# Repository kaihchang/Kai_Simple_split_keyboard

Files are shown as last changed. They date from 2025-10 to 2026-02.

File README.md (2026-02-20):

# Kai Simple, an easy-to-build diodeless, wireless split keyboard

Kai Simple is a cradio (or some call it Sweep) variation that fits author's hands best.
Author's first KB design: https://github.com/kaihchang/Ascend_splay_split_keyboard

👉 ZMK config | [Dongle-less](https://github.com/kaihchang/zmk-config-kai-simple) | [With Dongle](https://github.com/kaihchang/zmk-config-kai-simple-dongle)

MCUs face up for englmaxi's ZMK on-board LED widget. Front-facing built-in LEDs are utilized to present battery and connection status. I use n!n replicas, they only have 1 led each, so sadly no layer change indication.

| Images             |
:-------------------------:
New v4 case available!
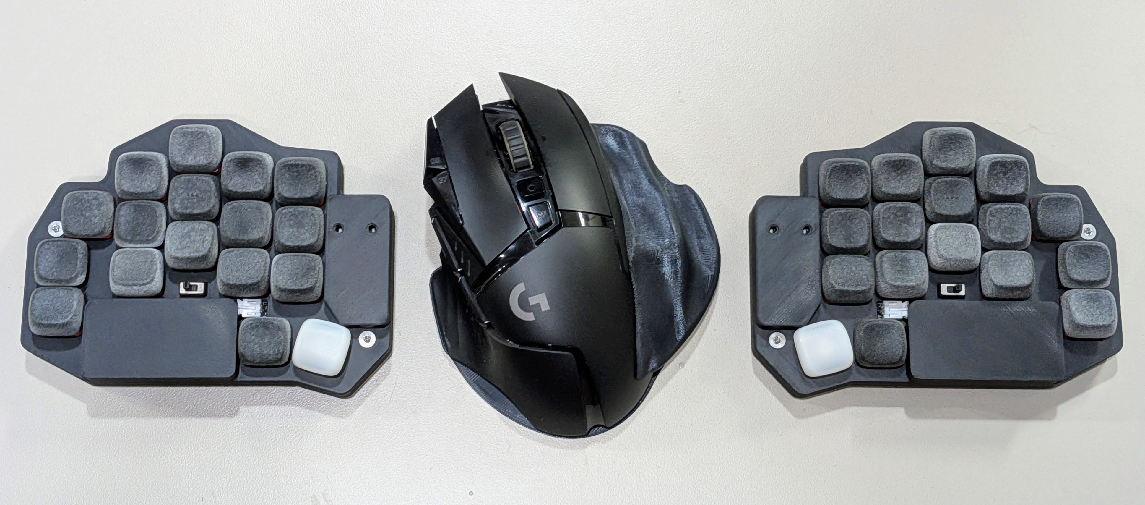
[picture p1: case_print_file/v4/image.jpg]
v4_case
|
|
  |
  |
螢幕擷取畫面 2024-04-08 094835  |

I've been using my last Ascend KB for a month, while it is comfortable, MX switches are still relatively big and wide. Maybe it's bc I have small hands or was used to Sweep before it, I started missing Chocs, so that's why there's this Simple.
I'll probably stick with ZMK but just in case something went wrong with the power circuits (unlikely), I left a pin for TRRS connectors.

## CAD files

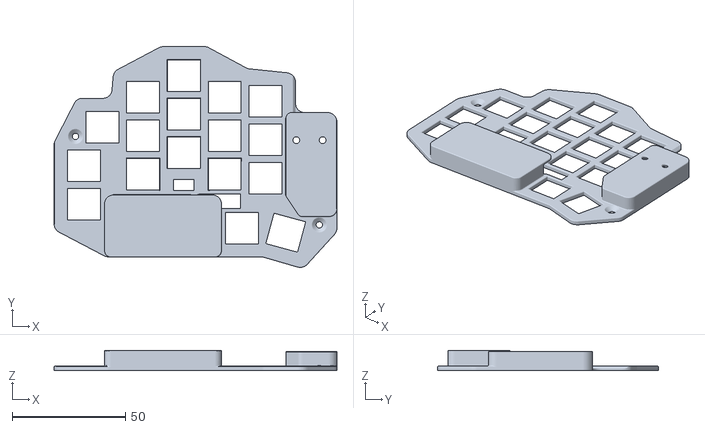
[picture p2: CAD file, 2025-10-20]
case_print_file/v4/upper_case_left.stl
124.9 x 97.5 x 8.89

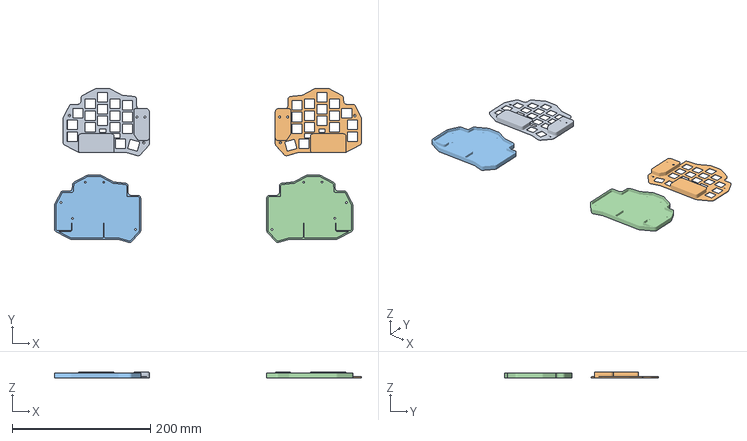
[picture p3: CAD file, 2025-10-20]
case_print_file/v4/kai_simple_cases_v4.3mf
444.6 x 223.0 x 8.89 mm
upper_case_left.stl x 2
lower_case_left.stl x 2

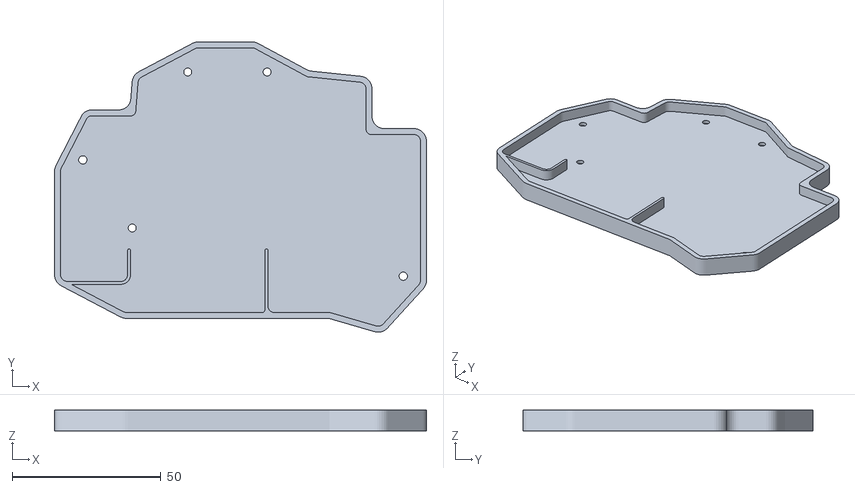
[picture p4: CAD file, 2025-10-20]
case_print_file/v4/lower_case_left.stl
124.9 x 97.5 x 7.00

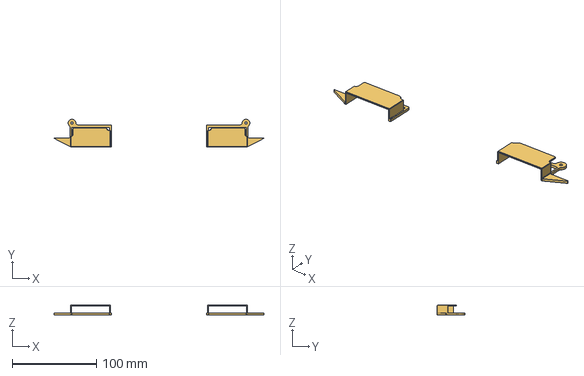
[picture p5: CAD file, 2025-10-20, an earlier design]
case_print_file/v1/v1_battery_cover.step
249.3 x 32.7 x 12.0 mm

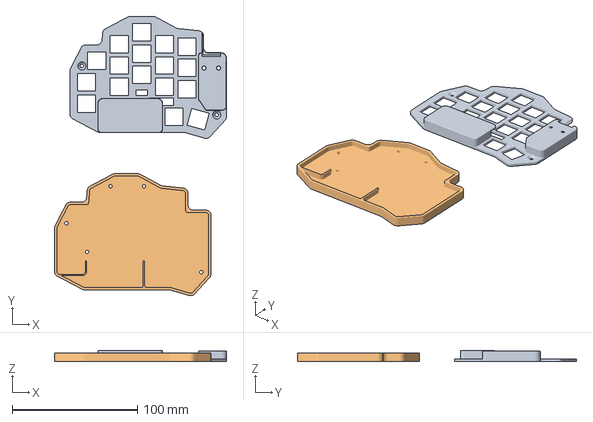
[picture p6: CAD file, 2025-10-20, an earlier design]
case_print_file/v3/kai_simple_cases_v3.3mf
137.3 x 223.0 x 8.89 mm
upper_case_left.stl
lower_case_left.stl

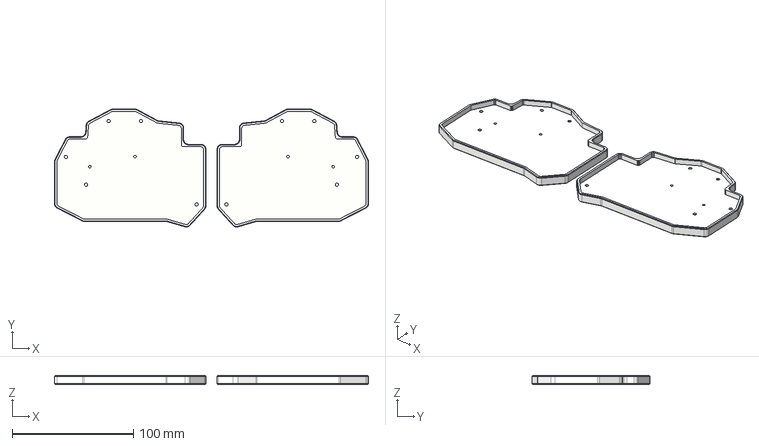
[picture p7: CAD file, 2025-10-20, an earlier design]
case_print_file/v1/v1_case.step
258.5 x 97.2 x 7.10 mm

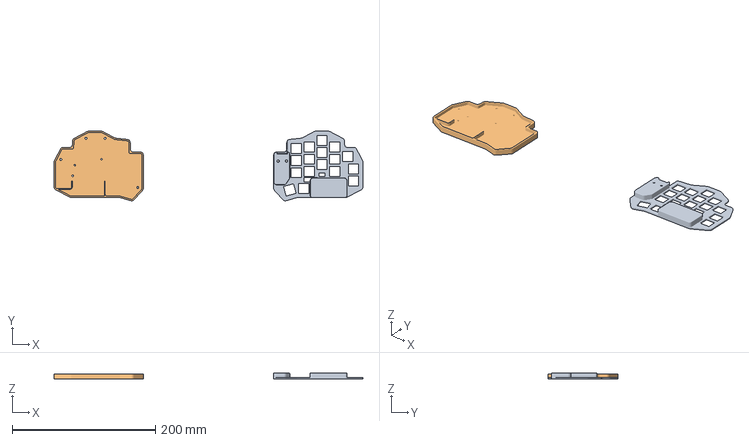
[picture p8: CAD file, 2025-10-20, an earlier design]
case_print_file/v2/kai_simple_cases_v2.3mf
432.1 x 97.5 x 8.89 mm
upper_case_left.stl
lower_case_left.stl

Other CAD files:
case_print_file/v2/upper_case_left.stl
case_print_file/v3/upper_case_left.stl

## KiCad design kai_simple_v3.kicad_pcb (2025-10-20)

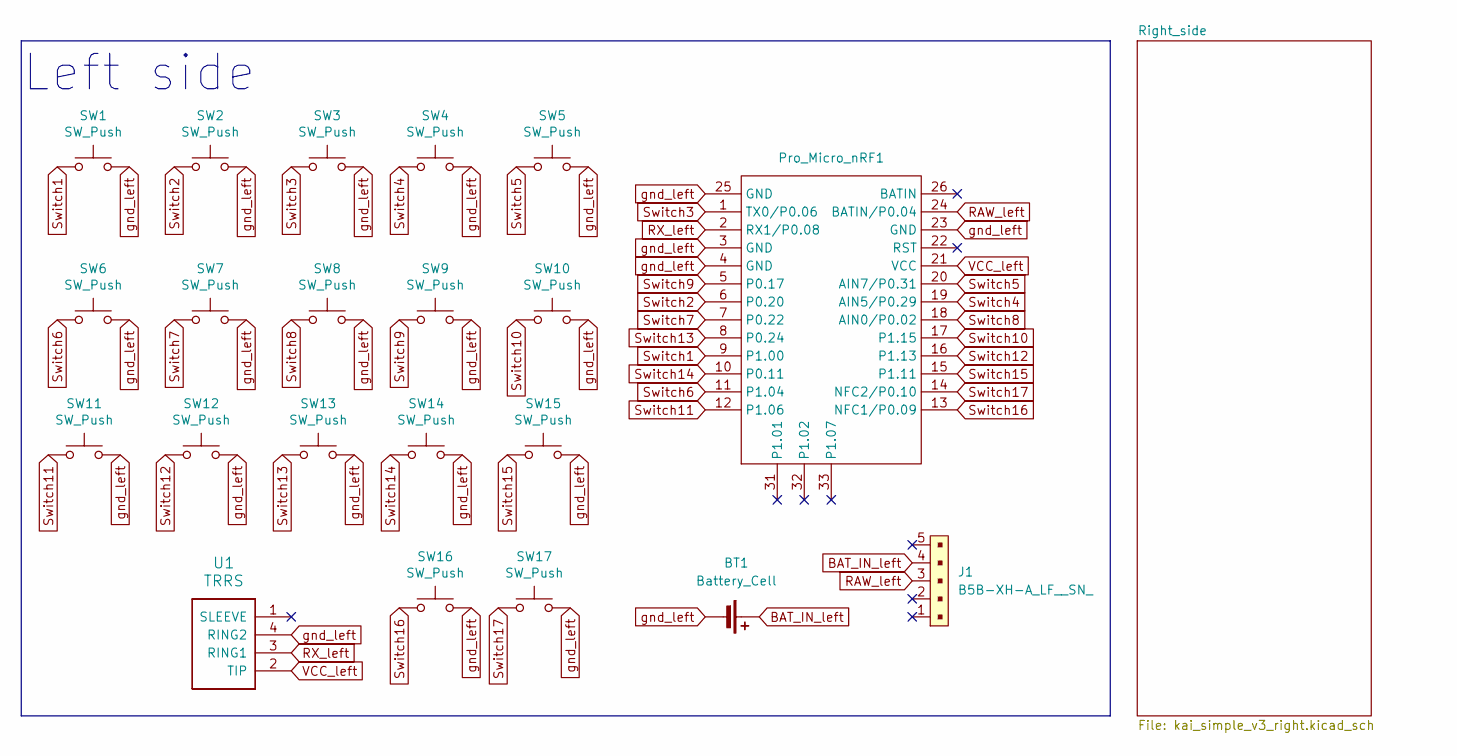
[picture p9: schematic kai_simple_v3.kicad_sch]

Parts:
BT1: Battery_Cell; JST_PH_reversible
J1: B5B-XH-A_LF__SN_; Switch_slide_TH_5P; MPN B5B-XH-A(LF)(SN); Digi-Key_PN 455-2270-ND
Pro_Micro_nRF1: Pro Micro nRF52840
SW1, SW2, SW3, SW4, SW5, SW6, SW7, SW8, SW9, SW10, SW11, SW12, SW13, SW14, SW15, SW16, SW17: SW_Push; Choc_v1v2_pretty
U1: TRRS; TRRS_PJ-320A

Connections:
BAT_IN_left: BT1.1 (+), J1.4
RAW_left: J1.3, Pro_Micro_nRF1.24 (BATIN/P0.04)
RX_left: Pro_Micro_nRF1.2 (RX1/P0.08), U1.3 (RING1)
Switch1: Pro_Micro_nRF1.9 (P1.00), SW1.1
Switch2: Pro_Micro_nRF1.6 (P0.20), SW2.1
Switch3: Pro_Micro_nRF1.1 (TX0/P0.06), SW3.1
Switch4: Pro_Micro_nRF1.19 (AIN5/P0.29), SW4.1
Switch5: Pro_Micro_nRF1.20 (AIN7/P0.31), SW5.1
Switch6: Pro_Micro_nRF1.11 (P1.04), SW6.1
Switch7: Pro_Micro_nRF1.7 (P0.22), SW7.1
Switch8: Pro_Micro_nRF1.18 (AIN0/P0.02), SW8.1
Switch9: Pro_Micro_nRF1.5 (P0.17), SW9.1
Switch10: Pro_Micro_nRF1.17 (P1.15), SW10.1
Switch11: Pro_Micro_nRF1.12 (P1.06), SW11.1
Switch12: Pro_Micro_nRF1.16 (P1.13), SW12.1
Switch13: Pro_Micro_nRF1.8 (P0.24), SW13.1
Switch14: Pro_Micro_nRF1.10 (P0.11), SW14.1
Switch15: Pro_Micro_nRF1.15 (P1.11), SW15.1
Switch16: Pro_Micro_nRF1.13 (NFC1/P0.09), SW16.1
Switch17: Pro_Micro_nRF1.14 (NFC2/P0.10), SW17.1
VCC_left: Pro_Micro_nRF1.21 (VCC), U1.2 (TIP)
gnd_left: BT1.2 (-), Pro_Micro_nRF1.3 (GND), Pro_Micro_nRF1.4 (GND), Pro_Micro_nRF1.23 (GND), Pro_Micro_nRF1.25 (GND), SW1.2, SW2.2, SW3.2, SW4.2, SW5.2, SW6.2, SW7.2, SW8.2, SW9.2, SW10.2, SW11.2, SW12.2, SW13.2, SW14.2, SW15.2, SW16.2, SW17.2, U1.4 (RING2)

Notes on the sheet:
Left side

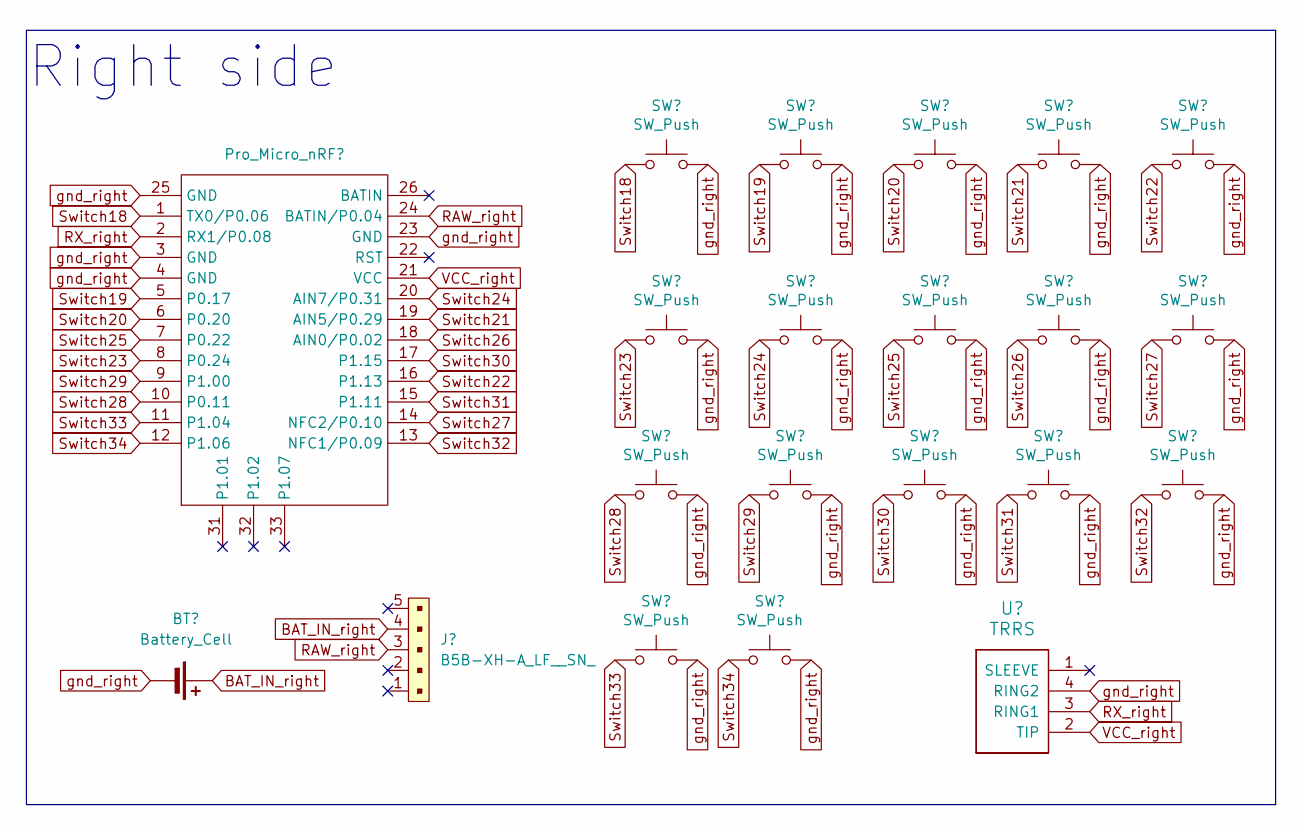
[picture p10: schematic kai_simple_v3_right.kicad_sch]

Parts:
BT2: Battery_Cell; JST_PH_reversible
J2: B5B-XH-A_LF__SN_; Switch_slide_TH_5P; MPN B5B-XH-A(LF)(SN); Digi-Key_PN 455-2270-ND
Pro_Micro_nRF2: Pro Micro nRF52840
SW18, SW19, SW20, SW21, SW22, SW23, SW24, SW25, SW26, SW27, SW28, SW29, SW30, SW31, SW32, SW33, SW34: SW_Push; Choc_v1v2_pretty
U2: TRRS; TRRS_PJ-320A

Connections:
BAT_IN_right: BT2.1 (+), J2.4
RAW_right: J2.3, Pro_Micro_nRF2.24 (BATIN/P0.04)
RX_right: Pro_Micro_nRF2.2 (RX1/P0.08), U2.3 (RING1)
Switch18: Pro_Micro_nRF2.1 (TX0/P0.06), SW18.1
Switch19: Pro_Micro_nRF2.5 (P0.17), SW19.1
Switch20: Pro_Micro_nRF2.6 (P0.20), SW20.1
Switch21: Pro_Micro_nRF2.19 (AIN5/P0.29), SW21.1
Switch22: Pro_Micro_nRF2.16 (P1.13), SW22.1
Switch23: Pro_Micro_nRF2.8 (P0.24), SW23.1
Switch24: Pro_Micro_nRF2.20 (AIN7/P0.31), SW24.1
Switch25: Pro_Micro_nRF2.7 (P0.22), SW25.1
Switch26: Pro_Micro_nRF2.18 (AIN0/P0.02), SW26.1
Switch27: Pro_Micro_nRF2.14 (NFC2/P0.10), SW27.1
Switch28: Pro_Micro_nRF2.10 (P0.11), SW28.1
Switch29: Pro_Micro_nRF2.9 (P1.00), SW29.1
Switch30: Pro_Micro_nRF2.17 (P1.15), SW30.1
Switch31: Pro_Micro_nRF2.15 (P1.11), SW31.1
Switch32: Pro_Micro_nRF2.13 (NFC1/P0.09), SW32.1
Switch33: Pro_Micro_nRF2.11 (P1.04), SW33.1
Switch34: Pro_Micro_nRF2.12 (P1.06), SW34.1
VCC_right: Pro_Micro_nRF2.21 (VCC), U2.2 (TIP)
gnd_right: BT2.2 (-), Pro_Micro_nRF2.3 (GND), Pro_Micro_nRF2.4 (GND), Pro_Micro_nRF2.23 (GND), Pro_Micro_nRF2.25 (GND), SW18.2, SW19.2, SW20.2, SW21.2, SW22.2, SW23.2, SW24.2, SW25.2, SW26.2, SW27.2, SW28.2, SW29.2, SW30.2, SW31.2, SW32.2, SW33.2, SW34.2, U2.4 (RING2)

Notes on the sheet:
Right side

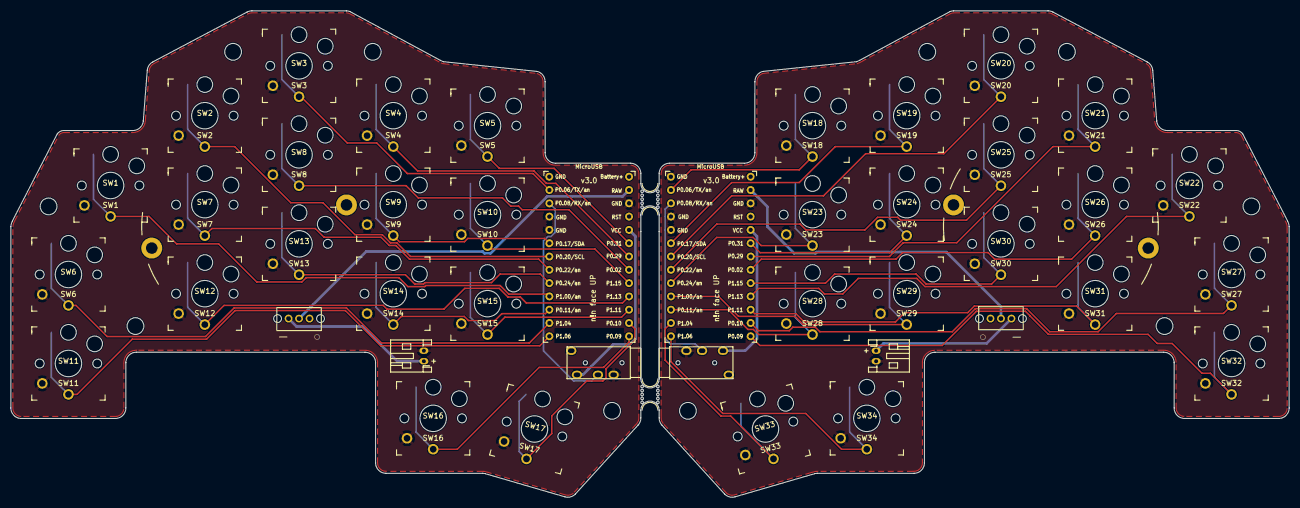
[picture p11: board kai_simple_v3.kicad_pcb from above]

Board: 2 copper layers, 244.2 x 92.9 mm, 44 parts (0 on the bottom side), 44 nets.

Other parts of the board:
mouse-bite-3mm-slot, mouse-bite-3mm-slot#2: VAL**; mouse-bite-3mm-slot

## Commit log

2025-10-20 add v2 & v3 case files
    [kai_simple_cases_v2.3mf, kai_simple_cases_v3.3mf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]
2025-10-20 add version 4 with 3mf file
    [kai_simple_cases_v4.3mf, lower_case_left.stl, upper_case_left.stl]
2026-02-20 Update README to include new v4 case details
    Added information about the new v4 case and included an image.
